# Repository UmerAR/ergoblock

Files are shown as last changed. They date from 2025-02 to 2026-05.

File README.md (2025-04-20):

# ErgoBlock
A wired split 3x6 column staggered keyboards with 3 thumb keys, an aggressive pinkie stagger, and low profile switches
PCB is also reversible

v1

maybe next keyboard i'll make it wireless
## Keymap
QWERTY layout with home row mods and a custom symbol and navigation layer. stuck with qwerty since I'm still in school, might switch to something more efficient in the future.

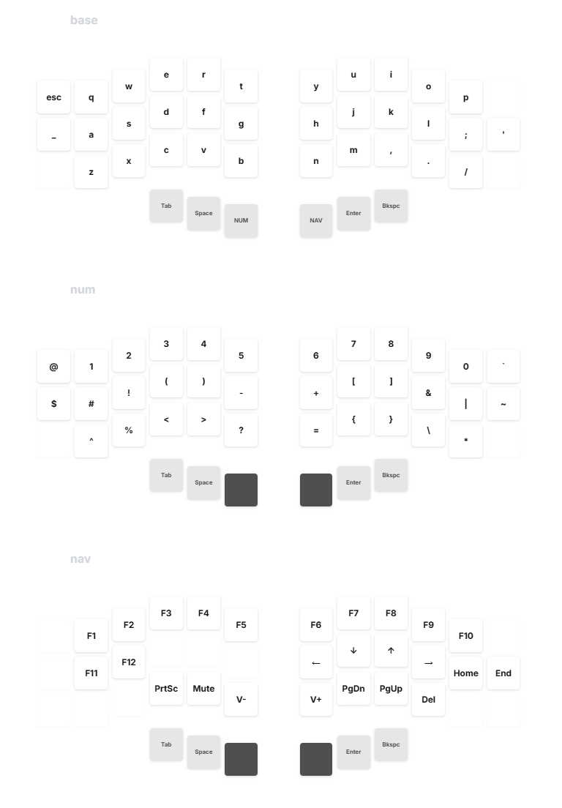
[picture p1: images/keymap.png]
keymap


## Parts
PCB was designed in KiCad using Ergogen and ordered using JLCPCB
All other parts were ordered from AliExpress
| Parts |Price ($)| Link |
|---|---|---|
|PCB |  16.57  |[JLCPCB](jlcpcb.com) |
|Keycaps (50pc) |  21.56  |[AliExpress](https://vi.aliexpress.com/item/1005006734545486.html)|
|hotswap sockets (10pc) x5 |  5.15 |[AliExpress](https://vi.aliexpress.com/item/32901654130.html) |
|Kalih pro red switches (70pcs)|  27.75  |[AliExpress](https://vi.aliexpress.com/item/1005005723938995.html)|
|diodes (100pc) |  1.31 |[AliExpress](https://vi.aliexpress.com/item/4000685043735.html) |
|trrs jack (10pc) |  1.21 |[AliExpress](https://vi.aliexpress.com/item/1005003111662179.html)|
|reset switch 4*4*1.5 (20pc) |  2.83 |[AliExpress](https://vi.aliexpress.com/item/1005005924012567.html)|
|promicro x2 |  8.70 |[AliExpress](https://vi.aliexpress.com/item/1005006654641959.html)|
|total |  85.08  |

## Author
- [@UmerAR](https://github.com/UmerAR)

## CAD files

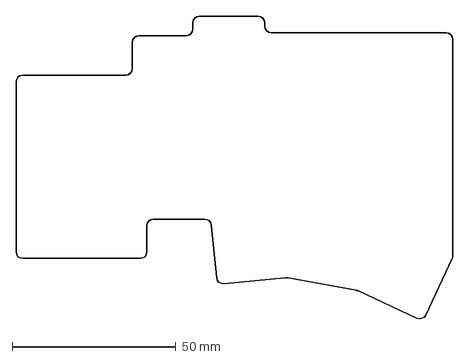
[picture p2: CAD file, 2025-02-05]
outlines/final_board.dxf
133.5 x 92.7 mm

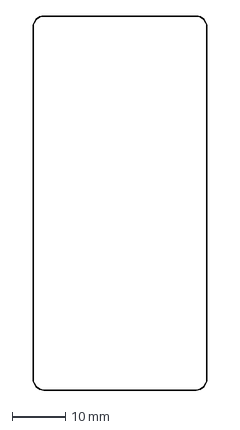
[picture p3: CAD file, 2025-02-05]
outlines/rectangle.dxf
32.5 x 70.0 mm

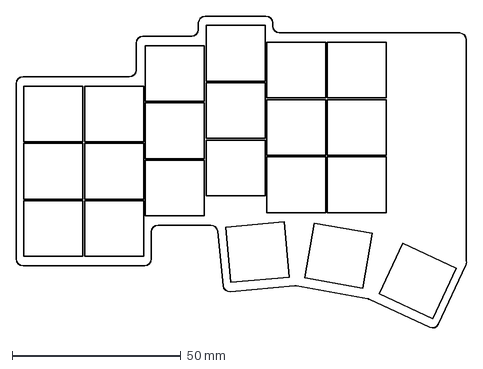
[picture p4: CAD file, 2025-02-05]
outlines/combo.dxf
133.5 x 92.7 mm

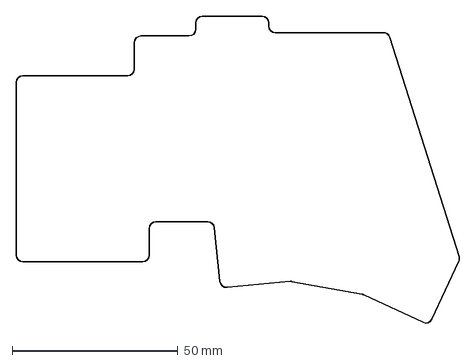
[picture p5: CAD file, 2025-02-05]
outlines/board.dxf
133.5 x 92.7 mm

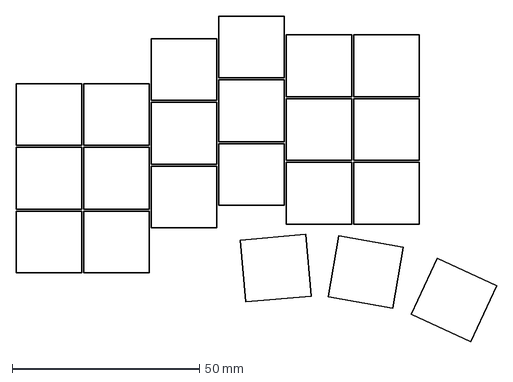
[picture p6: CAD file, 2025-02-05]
outlines/keys.dxf
128.2 x 86.9 mm

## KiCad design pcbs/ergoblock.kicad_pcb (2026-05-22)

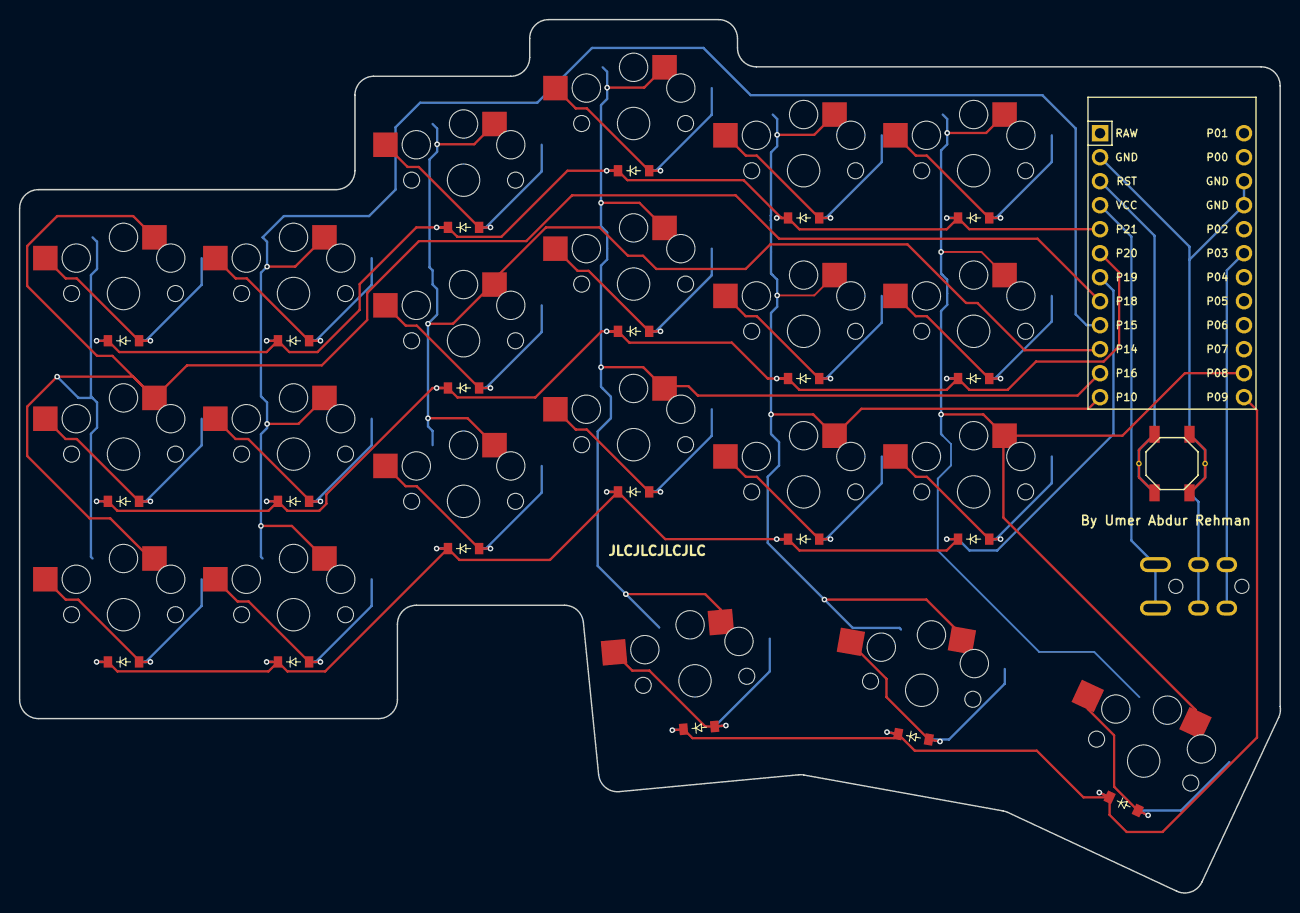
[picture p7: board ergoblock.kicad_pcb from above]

Board: 2 copper layers, 133.5 x 92.5 mm, 46 parts (0 on the bottom side), 35 nets.

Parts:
B1, B2: SW_TACT_ALPS_SKQGABE010
D1, D2, D3, D4, D5, D6, D7, D8, D9, D10, D11, D12, D13, D14, D15, D16, D17, D18, D19, D20, D21: diode_tht_sod123
MCU1: ProMicro
S1, S2, S3, S4, S5, S6, S7, S8, S9, S10, S11, S12, S13, S14, S15, S16, S17, S18, S19, S20, S21: PG1350
TRRS1: trrs_pj320a (reversible, symmetric)

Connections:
GND: B1.1, B2.1, MCU1.2, MCU1.15, MCU1.16, TRRS1.3
P3: MCU1.18, TRRS1.2
P8: MCU1.23, S16.1, S17.1, S18.1, S21.1
P9: D19.1, D20.1, D21.1, MCU1.24
P10: MCU1.12, S13.1, S14.1, S15.1, S20.1
P14: MCU1.10, S7.1, S8.1, S9.1
P15: MCU1.9, S4.1, S5.1, S6.1
P16: MCU1.11, S10.1, S11.1, S12.1, S19.1
P18: MCU1.8, S1.1, S2.1, S3.1
P19: D1.1, D4.1, D7.1, D10.1, D13.1, D16.1, MCU1.7
P20: D2.1, D5.1, D8.1, D11.1, D14.1, D17.1, MCU1.6
P21: D3.1, D6.1, D9.1, D12.1, D15.1, D18.1, MCU1.5
RST: B1.2, B2.2, MCU1.3
VCC: MCU1.4, TRRS1.4
index_bottom: D13.2, S13.2
index_home: D14.2, S14.2
index_top: D15.2, S15.2
inner_bottom: D16.2, S16.2
inner_cluster: D21.2, S21.2
inner_home: D17.2, S17.2
inner_top: D18.2, S18.2
middle_bottom: D10.2, S10.2
middle_cluster: D20.2, S20.2
middle_home: D11.2, S11.2
middle_top: D12.2, S12.2
outer_bottom: D1.2, S1.2
outer_cluster: D19.2, S19.2
outer_home: D2.2, S2.2
outer_top: D3.2, S3.2
pinkie_bottom: D4.2, S4.2
pinkie_home: D5.2, S5.2
pinkie_top: D6.2, S6.2
ring_bottom: D7.2, S7.2
ring_home: D8.2, S8.2
ring_top: D9.2, S9.2

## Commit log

2025-02-05 Added Keyboard and PCB design Files
    [board.dxf, combo.dxf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]
2025-02-05 Added PCB design files and keyboard design files
    [board.dxf, combo.dxf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]
2026-05-22 fixed firmware
    [ergoblock.kicad_pcb]
